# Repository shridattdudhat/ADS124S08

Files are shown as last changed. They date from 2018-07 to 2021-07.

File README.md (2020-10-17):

# ADS124S08

## 24-bit, 4-kSPS, 12-ch delta-sigma ADC with PGA and voltage reference for sensor measurement



24bit ADC | SPI









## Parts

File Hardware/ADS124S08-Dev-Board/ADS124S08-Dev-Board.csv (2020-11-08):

Qty | Value | Device | Package | Parts | Description | AVAILABILITY | DESCRIPTION | MF | MP | MPN | OC_FARNELL | PACKAGE | PRICE | PURCHASE-URL
1 |  | FERRITE_0603 | _0603 | FB1 | Ferrite Bead
1 | 0.1uF | CAP_CERAMIC0603MINI | C0603-MINI | C5 | Ceramic Capacitors |  |  | AVX |  | 08055C104JAT2A | 1740673
1 | 1uF | CAP_CERAMIC0603MINI | C0603-MINI | C1 | Ceramic Capacitors |  |  | AVX |  | 08055C104JAT2A | 1740673
1 | 330nF | CAP_CERAMIC0603MINI | C0603-MINI | C3 | Ceramic Capacitors |  |  | AVX |  | 08055C104JAT2A | 1740673
7 | 47R | RESISTOR0603MINI | R0603-MINI | R1, R2, R3, R4, R5, R6, R7 | Resistors
1 | ADS124S08-BOARD | ADS124S08-BOARD | ADS124S08-BOARD | U$1
1 | ADS124S08IPBSR | ADS124S08IPBSR | QFP50P700X700X120-32N | U1 | 24-Bit, 4kSPS, 12-Ch Delta-Sigma ADC With PGA and VREF for Precision Sensor Measurement 32-TQFP -50 to 125 Check prices | Good | 24-bit, 4-kSPS, 12-ch delta-sigma ADC with PGA and voltage reference for sensor measurement 32-TQFP -50 to 125 | Texas Instruments | ADS124S08IPBSR |  |  | TQFP-32 Texas Instruments | None | https://pricing.snapeda.com/search/part/ADS124S08IPBSR/?ref=eda
1 | OSHWLOGOLOGO5MM | OSHWLOGOLOGO5MM | OSHW_5MM | GOLD_ORB_SM1 | The OSHW logo for PCB layout
1 | OSHWLOGOLOGO8MM | OSHWLOGOLOGO8MM | OSHW_8MM | GOLD_ORB_SM2 | The OSHW logo for PCB layout

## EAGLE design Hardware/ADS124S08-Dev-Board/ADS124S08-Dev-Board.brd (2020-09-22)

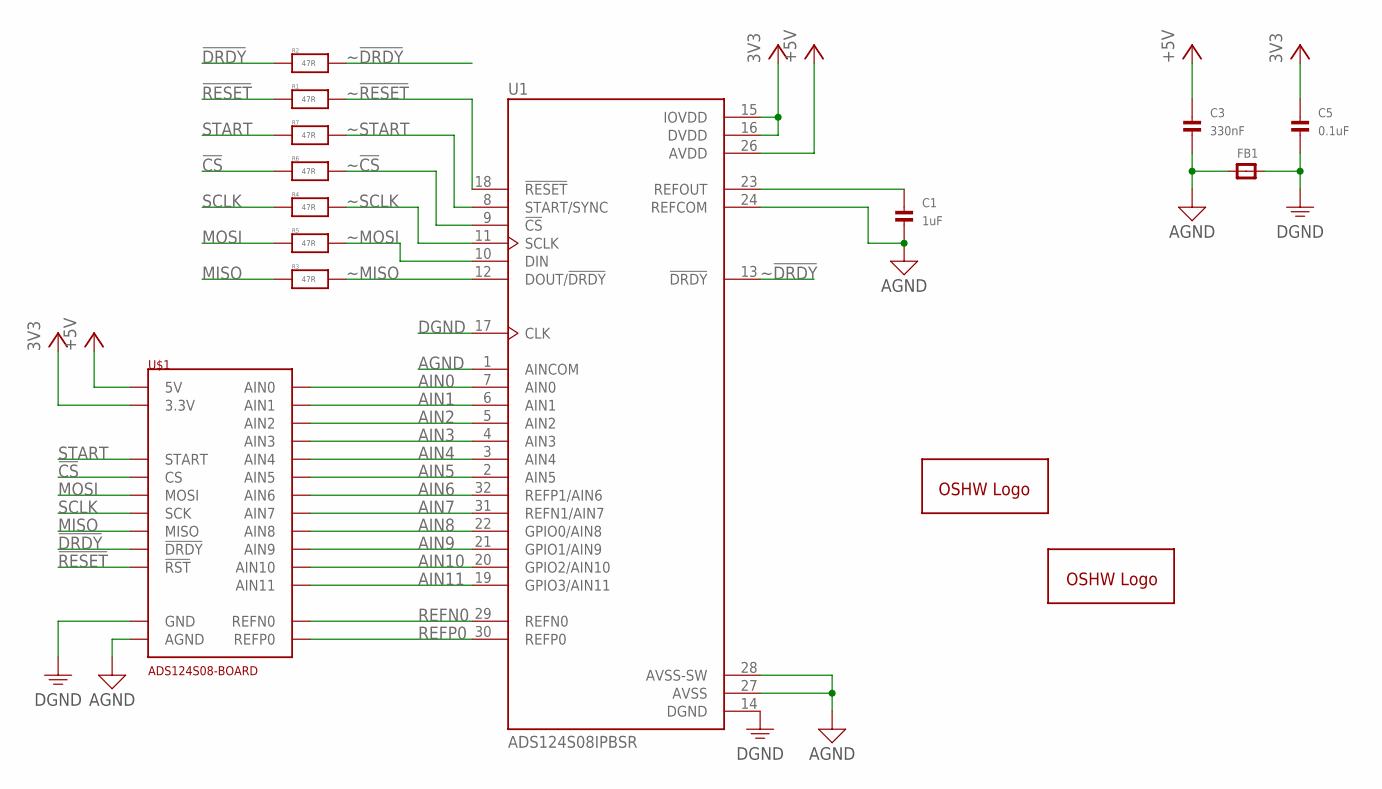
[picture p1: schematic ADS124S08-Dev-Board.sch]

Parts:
C1: 1uF; C0603-MINI; MPN 08055C104JAT2A
C3: 330nF; C0603-MINI; MPN 08055C104JAT2A
C5: 0.1uF; C0603-MINI; MPN 08055C104JAT2A
FB1: FERRITE_0603; _0603
GOLD_ORB_SM1: OSHWLOGOLOGO5MM; OSHW_5MM
GOLD_ORB_SM2: OSHWLOGOLOGO8MM; OSHW_8MM
R1, R2, R3, R4, R5, R6, R7: 47R; R0603-MINI
U1: ADS124S08IPBSR; QFP50P700X700X120-32N
U$1: ADS124S08-BOARD

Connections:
3V3: C5.1, U1.15 (IOVDD), U1.16 (DVDD), U$1.15 (3.3V)
!CS: R6.1, U$1.21 (CS)
!DRDY: R2.1, U$1.17 (!DRDY)
!RESET: R1.1, U$1.16 (!RST)
+5V: C3.1, U1.26 (AVDD), U$1.14 (5V)
AGND: C1.2, C3.2, FB1.1, U1.1 (AINCOM), U1.24 (REFCOM), U1.27 (AVSS), U1.28 (AVSS-SW), U$1.25 (AGND)
AIN0: U1.7 (AIN0), U$1.12 (AIN0)
AIN1: U1.6 (AIN1), U$1.11 (AIN1)
AIN2: U1.5 (AIN2), U$1.10 (AIN2)
AIN3: U1.4 (AIN3), U$1.9 (AIN3)
AIN4: U1.3 (AIN4), U$1.8 (AIN4)
AIN5: U1.2 (AIN5), U$1.7 (AIN5)
AIN6: U1.32 (REFP1/AIN6), U$1.6 (AIN6)
AIN7: U1.31 (REFN1/AIN7), U$1.5 (AIN7)
AIN8: U1.22 (GPIO0/AIN8), U$1.4 (AIN8)
AIN9: U1.21 (GPIO1/AIN9), U$1.3 (AIN9)
AIN10: U1.20 (GPIO2/AIN10), U$1.2 (AIN10)
AIN11: U1.19 (GPIO3/AIN11), U$1.1 (AIN11)
DGND: C5.2, FB1.2, U1.14 (DGND), U1.17 (CLK), U$1.13 (GND), U$1.26 (GND)
MISO: R3.1, U$1.18 (MISO)
MOSI: R5.1, U$1.20 (MOSI)
unnamed: C1.1, U1.23 (REFOUT)
REFN0: U1.29 (REFN0), U$1.23 (REFN0)
REFP0: U1.30 (REFP0), U$1.24 (REFP0)
SCLK: R4.1, U$1.19 (SCK)
START: R7.1, U$1.22 (START)
~!CS: R6.2, U1.9 (!CS)
~!DRDY: R2.2, U1.13 (!DRDY)
~!RESET: R1.2, U1.18 (!RESET)
~MISO: R3.2, U1.12 (DOUT/!DRDY)
~MOSI: R5.2, U1.10 (DIN)
~SCLK: R4.2, U1.11 (SCLK)
~START: R7.2, U1.8 (START/SYNC)

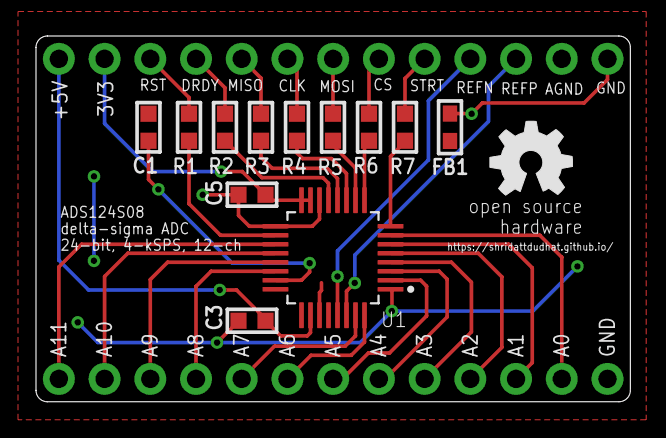
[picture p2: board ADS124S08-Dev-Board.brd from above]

Board: 2 copper layers, 33.0 x 20.3 mm, 15 parts (1 on the bottom side), 33 nets.

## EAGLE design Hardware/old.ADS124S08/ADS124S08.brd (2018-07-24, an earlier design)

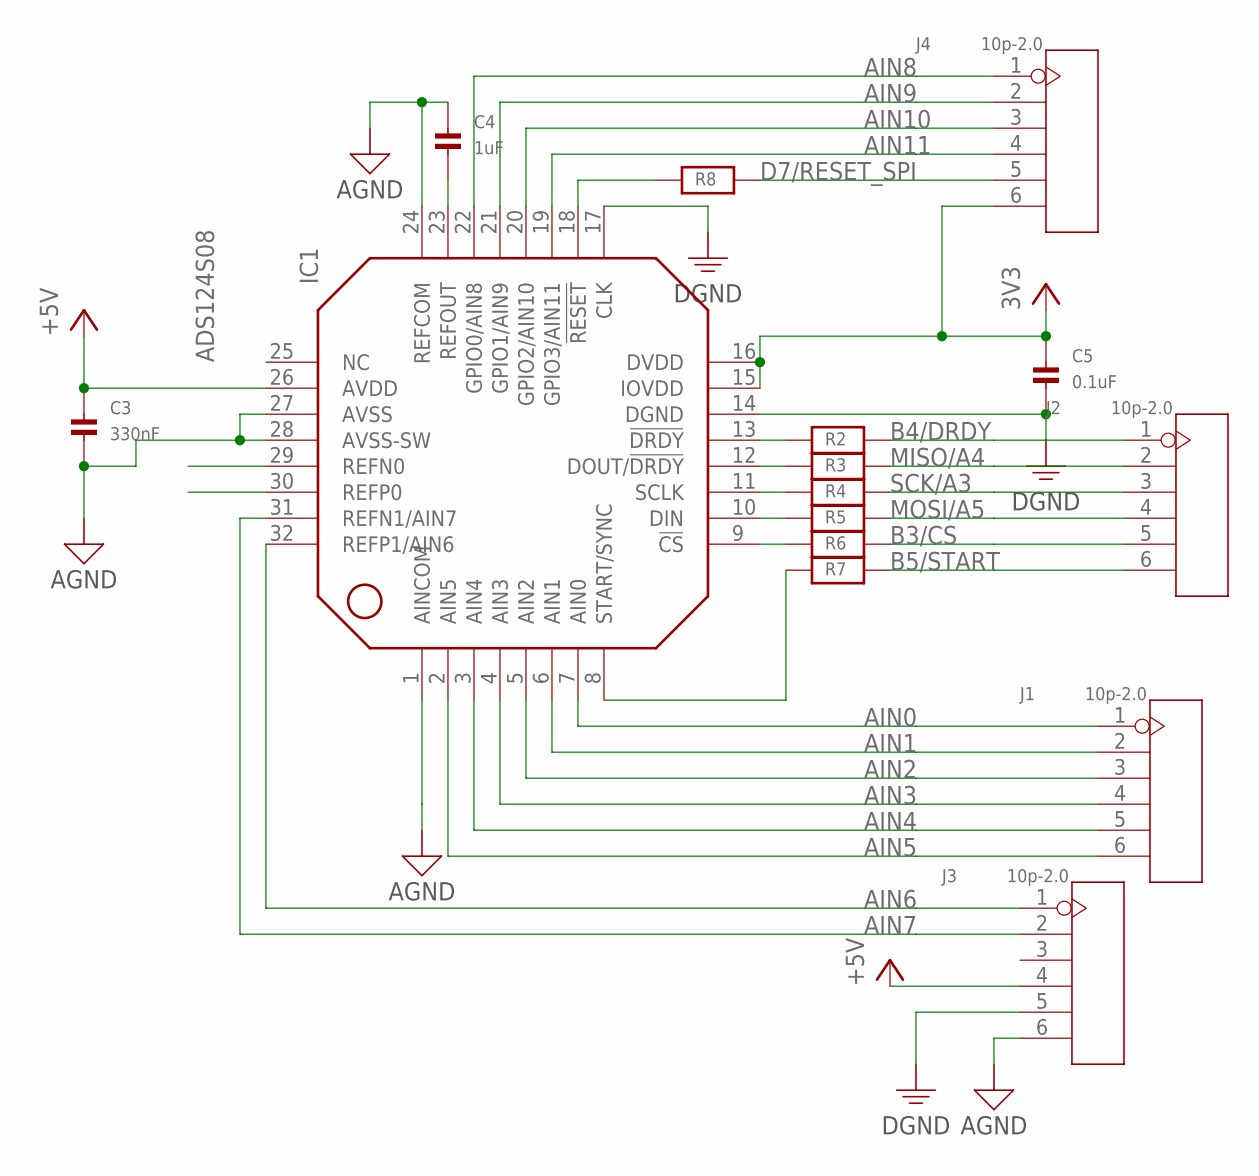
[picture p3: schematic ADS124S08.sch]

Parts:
C3: 330nF; 0805; MPN 08055C104JAT2A
C4: 1uF; 0805; MPN 08055C104JAT2A
C5: 0.1uF; 0805; MPN 08055C104JAT2A
IC1: ADS124S08
J1, J2, J3, J4: 10p-2.0; H10-2.0
R2, R3, R4, R5, R7, R8: 47; 0603
R6: RESISTOR0603; 0603

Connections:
3V3: C5.1, IC1.15 (IOVDD), IC1.16 (DVDD), J4.6
!RESET: IC1.18 (!RESET), R8.1
+5V: C3.1, IC1.26 (AVDD), J3.4
AGND: C3.2, C4.1, IC1.1 (AINCOM), IC1.24 (REFCOM), IC1.27 (AVSS), IC1.28 (AVSS-SW), J3.6
AIN0: IC1.7 (AIN0), J1.1
AIN1: IC1.6 (AIN1), J1.2
AIN2: IC1.5 (AIN2), J1.3
AIN3: IC1.4 (AIN3), J1.4
AIN4: IC1.3 (AIN4), J1.5
AIN5: IC1.2 (AIN5), J1.6
AIN6: IC1.32 (REFP1/AIN6), J3.1
AIN7: IC1.31 (REFN1/AIN7), J3.2
AIN8: IC1.22 (GPIO0/AIN8), J4.1
AIN9: IC1.21 (GPIO1/AIN9), J4.2
AIN10: IC1.20 (GPIO2/AIN10), J4.3
AIN11: IC1.19 (GPIO3/AIN11), J4.4
B3/CS: J2.5, R6.2
B4/DRDY: J2.1, R2.2
B5/START: J2.6, R7.2
CS: IC1.9 (!CS), R6.1
D7/RESET_SPI: J4.5, R8.2
DGND: C5.2, IC1.14 (DGND), IC1.17 (CLK), J3.5
DRDY: IC1.13 (!DRDY), R2.1
MISO: IC1.12 (DOUT/!DRDY), R3.1
MISO/A4: J2.2, R3.2
MOSI: IC1.10 (DIN), R5.1
MOSI/A5: J2.4, R5.2
REFOUT: C4.2, IC1.23 (REFOUT)
SCK: IC1.11 (SCLK), R4.1
SCK/A3: J2.3, R4.2
START: IC1.8 (START/SYNC), R7.1

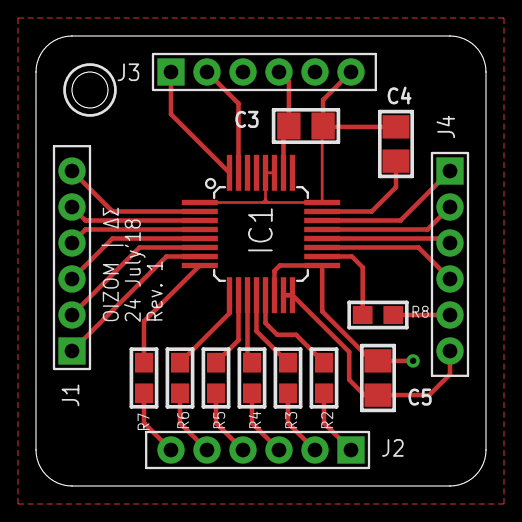
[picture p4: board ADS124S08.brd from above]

Board: 2 copper layers, 25.0 x 25.0 mm, 15 parts (0 on the bottom side), 31 nets.

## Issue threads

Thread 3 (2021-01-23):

Ferrite bead part number

Merlin04, 2021-01-23:
I'm looking into building one of these boards (I'd buy it from your Tindie store but shipping would be $50), and I was able to find all of the parts on DigiKey except for the ferrite bead. There are [a lot of options](https://www.digikey.com/en/products/filter/ferrite-beads-and-chips/841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) and I don't know what parameters are needed. Could you provide the part number you are using?

shridattdudhat, 2021-02-02:
Hi,

Sorry for the late reply. I know the shipping charges are too high. I am searching for cheap shipping options in my locality. Anyway, you can always build the board by yourself!

For the ferrite bead, you can use https://www.digikey.com/en/products/detail/fair-rite-products-corp/2506036007Y3/8594266
It has very low DC resistance 40mOhm and 60Ohm at 100Mhz.

The main function of the ferrite bead is to reduce switching noise and keep the analogue reading undisturbed from digital signals.

Thank you.

Merlin04, 2021-02-02:
Ok, thank you so much!

Closed 2021-02-02.

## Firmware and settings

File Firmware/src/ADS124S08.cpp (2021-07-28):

#include "ADS124S08.h"
#include "math.h"

ADS124S08::ADS124S08()
{
  pinMode(ADS124S08_DRDY_PIN, INPUT);                  //data ready input line
  pinMode(ADS124S08_START_PIN, OUTPUT);               // start
  pinMode(ADS124S08_PWDN_PIN, OUTPUT);                // Power down output
}

// return mV value
float ADS124S08::ADS124S08_Read_Data()
{
  float value = -1;
  if(digitalRead(ADS124S08_DRDY_PIN) == LOW)               // monitor Data ready(DRDY pin)
  {
    while(digitalRead(ADS124S08_DRDY_PIN) == LOW);

    uint32_t iData = 0;
    digitalWrite(ADS124S08_CS_PIN, LOW);
    delay(5);
    iData = SPI.transfer(CONFIG_SPI_MASTER_DUMMY);
    iData = (iData<<8) + SPI.transfer(CONFIG_SPI_MASTER_DUMMY);
    iData = (iData<<8) + SPI.transfer(CONFIG_SPI_MASTER_DUMMY);
    delay(5);
    digitalWrite(ADS124S08_CS_PIN, HIGH);

    value = (RES) * (float)iData * 1000;
  	return value;
  }
  else
  {
    return value;
  }
}

uint32_t ADS124S08::ADS124S08_Read()
{
  uint32_t iData = 0;
  uint8_t rxBuffer[3] = {0};

  digitalWrite(ADS124S08_CS_PIN,LOW);
  delay(5);
  SPI.transfer(ADS_RDATA);
  //SPI.transfer(0x00);
  rxBuffer[0] = SPI.transfer(0x00);
	rxBuffer[1] = SPI.transfer(0x00);
  rxBuffer[2] = SPI.transfer(0x00);
  //SPI.transfer(0x00);
  delay(5);
  digitalWrite(ADS124S08_CS_PIN,HIGH);

  Serial.println(rxBuffer[0]);
  Serial.println(rxBuffer[1]);
  Serial.println(rxBuffer[2]);

  iData = (rxBuffer[0] << 16) + (rxBuffer[1] << 8) + rxBuffer[2];
	return iData;
}

uint8_t ADS124S08::readRegister(uint8_t address)
{
  uint8_t data;
  uint8_t data1;
  digitalWrite(ADS124S08_CS_PIN,LOW);
  delay(5);
  SPI.transfer(ADS_RREG|(address & 0x1f));
  SPI.transfer(0x00);
  data = SPI.transfer(CONFIG_SPI_MASTER_DUMMY);
  delay(5);
  digitalWrite(ADS124S08_CS_PIN,HIGH);
  return data;
}

void ADS124S08::ADS124S08_Init()
{
  // Log.info("ADS Init");
  delay(10);
  ADS124S08_Reset();
  delay(20);
  ADS124S08_Reset_Data_Conv_Command();
  delay(1000);

  ADS124S08_Reg_Write(ADS_INPMUX, 0x0C);	//Ch 1 enabled, gain 6, connected to electrode in
  delay(10);
  ADS124S08_Reg_Write(ADS_REF, 0x1A);	//Ch 1 enabled, gain 6, connected to electrode in
  delay(10);

  ADS124S08_Enable_Start();
  delay(10);
  ADS124S08_Disable_Start();
  delay(50);

  ADS124S08_Start_Data_Conv_Command();
  delay(50);
}

void ADS124S08::setChannel(uint8_t channel)
{
  channel = (channel << 4) + 0x0C;
  ADS124S08_Reg_Write(ADS_INPMUX, channel);	//Ch 1 enabled, gain 6, connected to electrode in
  delay(10);
}

void ADS124S08::ADS124S08_Reset()
{
  digitalWrite(ADS124S08_PWDN_PIN, HIGH);
  delay(100);					// Wait 100 mSec
  digitalWrite(ADS124S08_PWDN_PIN, LOW);
  delay(100);
  digitalWrite(ADS124S08_PWDN_PIN, HIGH);
  delay(100);
}

void ADS124S08::ADS124S08_Disable_Start()
{
  digitalWrite(ADS124S08_START_PIN, LOW);
  delay(20);
}

void ADS124S08::ADS124S08_Enable_Start()
{
  digitalWrite(ADS124S08_START_PIN, HIGH);
  delay(20);
}

void ADS124S08::ADS124S08_Hard_Stop (void)
{
  digitalWrite(ADS124S08_START_PIN, LOW);
  delay(100);
}

void ADS124S08::ADS124S08_Reset_Data_Conv_Command (void)
{
  ADS124S08_SPI_Command_Data(ADS_RESET);					// Send 0x08 to the ADS1x9x
}


void ADS124S08::ADS124S08_Start_Data_Conv_Command (void)
{
  ADS124S08_SPI_Command_Data(ADS_START);					// Send 0x08 to the ADS1x9x
}

void ADS124S08::ADS124S08_Wakeup_Data_Conv_Command (void)
{
  ADS124S08_SPI_Command_Data(ADS_WAKEUP);					// Send 0x08 to the ADS1x9x
}

void ADS124S08::ADS124S08_Soft_Stop (void)
{
  ADS124S08_SPI_Command_Data(ADS_STOP);                   // Send 0x0A to the ADS1x9x
}

void ADS124S08::ADS124S08_Start_Read_Data_Continuous (void)
{

}

void ADS124S08::ADS124S08_Stop_Read_Data_Continuous (void)
{

}

void ADS124S08::ADS124S08_SPI_Command_Data(unsigned char data_in)
{
  digitalWrite(ADS124S08_CS_PIN, LOW);
  delay(2);
  SPI.transfer(data_in);
  delay(2);
  digitalWrite(ADS124S08_CS_PIN, HIGH);
}

//Sends a write command to SCP1000
void ADS124S08::ADS124S08_Reg_Write (unsigned char READ_WRITE_ADDRESS, unsigned char DATA)
{
  // now combine the register address and the command into one byte:
  byte dataToSend = READ_WRITE_ADDRESS + ADS_WREG;
  // take the chip select low to select the device:
  digitalWrite(ADS124S08_CS_PIN, LOW);
  delay(2);
  SPI.transfer(dataToSend); //Send register location
  SPI.transfer(0x00);		//number of register to wr
  SPI.transfer(DATA);		//Send value to record into register
  delay(2);
  // take the chip select high to de-select:
  digitalWrite(ADS124S08_CS_PIN, HIGH);
}

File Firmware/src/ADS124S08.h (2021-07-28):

/*
ADS124S08.h - Library for ADS124S08 
Released into the public domain.
*/

#ifndef ADS124S08_h
#define ADS124S08_h

// Includes
#include "Arduino.h"
#include <SPI.h>

#define CONFIG_SPI_MASTER_DUMMY   0x00
#define VREF 2.5
#define RES (double)((double)VREF/pow(2,23))

// Register Read Commands
#define ADS_RREG   0x20		//Read n nnnn registers starting at address r rrrr
                              //first byte 001r rrrr (2xh)(2) - second byte 000n nnnn(2)
#define ADS_WREG    0x40		//Write n nnnn registers starting at address r rrrr
                              //first byte 010r rrrr (2xh)(2) - second byte 000n nnnn(2)
#define ADS_WAKEUP  0x02
#define ADS_RESET		0x06
#define ADS_START		0x08		//Start/restart (synchronize) conversions
#define ADS_STOP		0x0A		//Stop conversion
#define ADS_RDATA		0x12		//Read data by command; supports multiple read back.

#define	ADS_INPMUX		0x02
#define	ADS_REF		    0x05

//Pin declartion the other you need are controlled by the SPI library
const int ADS124S08_DRDY_PIN = 10;
const int ADS124S08_CS_PIN = 11;
const int ADS124S08_START_PIN = 12;
const int ADS124S08_PWDN_PIN = 13;

class ADS124S08
{
public:
  ADS124S08();
  void ADS124S08_Init(void);
  void ADS124S08_Reset(void);
  void ADS124S08_Reg_Write (unsigned char READ_WRITE_ADDRESS, unsigned char DATA);
  void ADS124S08_Reg_Read (unsigned char READ_WRITE_ADDRESS);
  void ADS124S08_SPI_Command_Data(unsigned char data_in);
  void ADS124S08_Disable_Start(void);
  void ADS124S08_Enable_Start(void);
  void ADS124S08_Hard_Stop (void);
  void ADS124S08_Start_Data_Conv_Command (void);
  void ADS124S08_Soft_Stop (void);
  void ADS124S08_Start_Read_Data_Continuous (void);
  void ADS124S08_Wakeup_Data_Conv_Command(void);
  void ADS124S08_Stop_Read_Data_Continuous (void);
  void ADS124S08_Reset_Data_Conv_Command(void);
  float ADS124S08_Read_Data(void);
  uint32_t ADS124S08_Read();
  uint8_t readRegister(uint8_t address);
  void setChannel(uint8_t channel);
};

#endif

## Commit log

2018-07-24 SCH | PCB
    [ADS124S08.brd, ADS124S08.sch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]
2020-09-16 new updates | Creation of new Dev Module for ADS124S08 IC
    [ADS124S08-Dev-Board.brd, ADS124S08-Dev-Board.sch, ADS124S08.brd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]
2020-09-16 new Board SCH
2020-09-16 Component placement done
    [ADS124S08-Dev-Board.brd, ADS124S08-Dev-Board.sch]
2020-09-22 GERBER GENERATION
    [ADS124S08-Dev-Board.brd]
2021-07-28 Arduino Example

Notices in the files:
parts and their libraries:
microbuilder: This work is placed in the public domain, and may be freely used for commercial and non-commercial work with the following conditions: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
